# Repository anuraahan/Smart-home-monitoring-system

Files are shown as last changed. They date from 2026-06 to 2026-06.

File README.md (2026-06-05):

Node designs along with PCB and Schematic files in Node folder 
Node 2 is a better design with seperate ENS160 and AHT21 sensors so temperature less affected by heat from ENS160 
The code may have to be adjusted to get the right temp offset 
Screen code is an 2.8 inch ESP32-S3 from freenove 
https://docs.freenove.com/projects/fnk0104/en/latest/

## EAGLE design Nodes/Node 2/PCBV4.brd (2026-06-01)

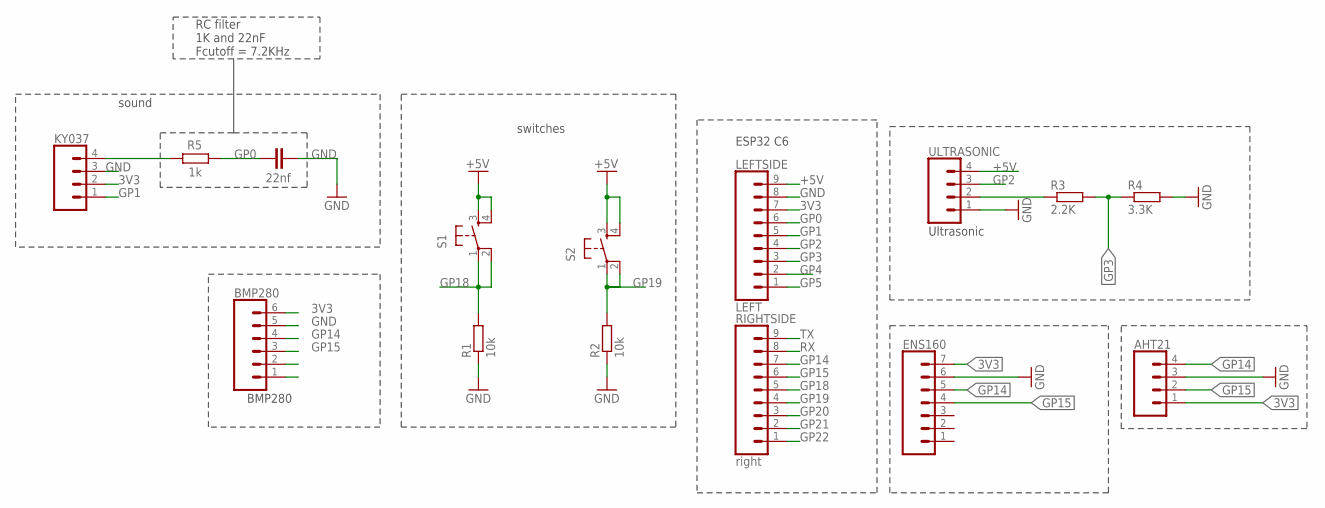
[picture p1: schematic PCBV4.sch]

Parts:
AHT21: CONN_04LONGPADS; 1X04_LONGPADS
BMP280: BMP280; SPARKFUN-CONNECTORS_1X06_LONGPADS
C1: 22nf; CAPACITOR-WIMA_C2.5-2
ENS160: CONN_07; 1X07
KY037: 1X04_SMD_STRAIGHT_COMBO; 1X04_LONGPADS
LEFTSIDE: LEFT; 1X09
R1, R2: 10k; 0207/10
R3: 2.2K; 0207/10
R4: 3.3K; 0207/10
R5: 1k; 0207/10
RIGHTSIDE: right; 1X09
S1, S2: EL311-ROBOT_SPARKFUN-ELECTROMECHANICAL_TAC_SWITCH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; EL311-ROBOT_SPARKFUN-ELECTROMECHANICAL_TACTILE-PTH
ULTRASONIC: 1X04_SMD_STRAIGHT_COMBO; 1X04_LONGPADS

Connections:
3V3: AHT21.1, BMP280.6, ENS160.7, KY037.2, LEFTSIDE.7
+5V: LEFTSIDE.9, S1.3, S1.4, S2.3, S2.4, ULTRASONIC.4
GND: AHT21.3, BMP280.5, C1.2, ENS160.6, KY037.3, LEFTSIDE.8, R1.1, R2.1, R4.2, ULTRASONIC.1
GP0: C1.1, LEFTSIDE.6, R5.1
GP1: KY037.1, LEFTSIDE.5
GP2: LEFTSIDE.4, ULTRASONIC.3
GP3: LEFTSIDE.3, R3.2, R4.1
GP4: LEFTSIDE.2
GP5: LEFTSIDE.1
GP14: AHT21.4, BMP280.4, ENS160.5, RIGHTSIDE.7
GP15: AHT21.2, BMP280.3, ENS160.4, RIGHTSIDE.6
GP18: R1.2, RIGHTSIDE.5, S1.1, S1.2
GP19: R2.2, RIGHTSIDE.4, S2.1, S2.2
GP20: RIGHTSIDE.3
GP21: RIGHTSIDE.2
GP22: RIGHTSIDE.1
unnamed: KY037.4, R5.2
unnamed: R3.1, ULTRASONIC.2
RX: RIGHTSIDE.8
TX: RIGHTSIDE.9

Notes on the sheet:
ESP32 C6
switches
Ultrasonic
BMP280
sound
RC filter 1K and 22nF Fcutoff = 7.2KHz

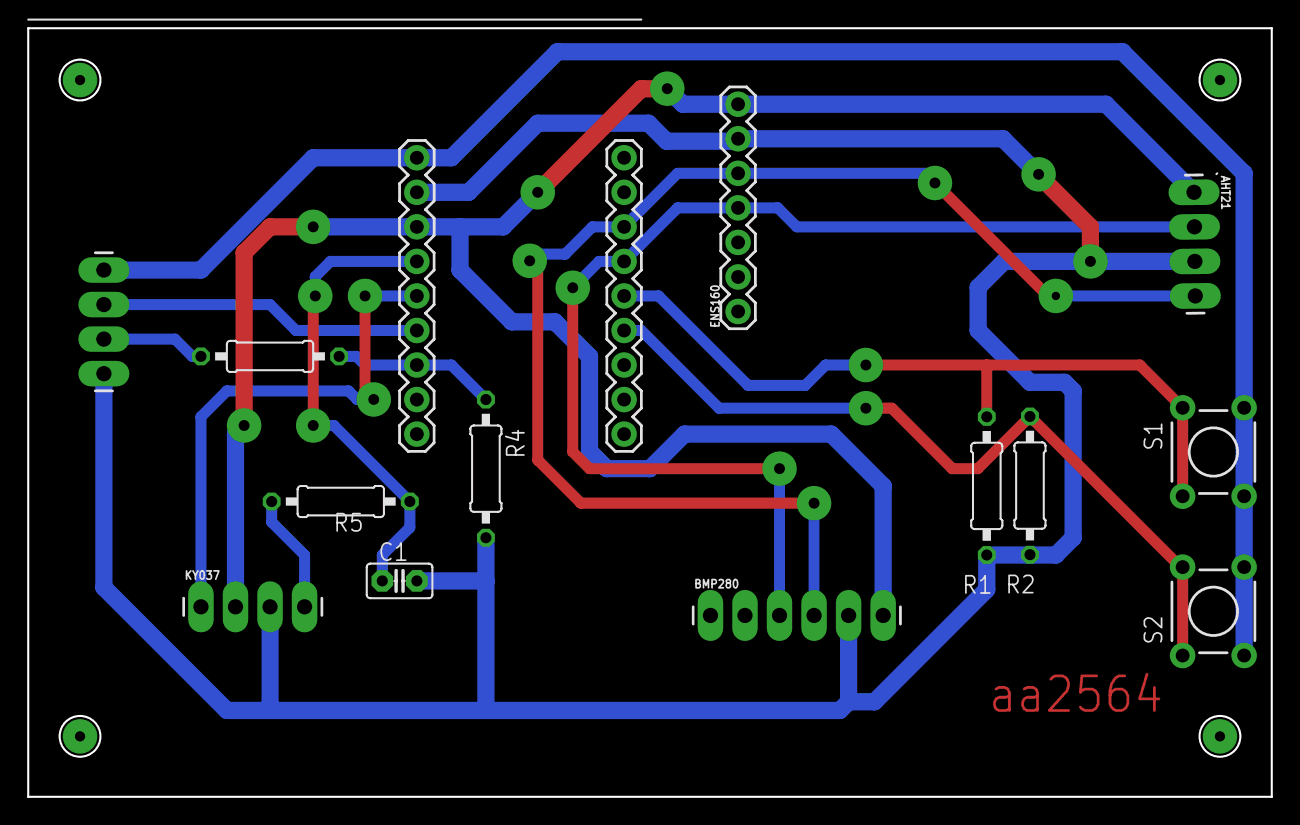
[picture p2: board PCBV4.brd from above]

Board: 2 copper layers, 91.4 x 56.5 mm, 15 parts (0 on the bottom side), 13 nets.

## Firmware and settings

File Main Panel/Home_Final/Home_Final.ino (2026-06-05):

/*
Smart Home Area Network (HAN) - Master Display & Server Node
Target Hardware: ESP32-S3 with TFT_eSPI Display, FT6336U Touch, and SD Card
This programme acts as a central hub, receiving JSON data from sensor nodes,
logging it to an SD card, displaying real-time metrics on a touchscreen GUI, 
and serving a web dashboard via an asynchronous web server.
 */

#include <WiFi.h>
#include <ESPAsyncWebServer.h>
#include <TFT_eSPI.h>
#include "FT6336U.h"
#include "FS.h"
#include "SD.h" 
#include "SPI.h"
#include "time.h" 
#include <ArduinoJson.h> 
#include "AsyncJson.h" // Required for ESPAsyncWebServer JSON extraction

// WiFi Configuration  
const char* ssid = "EDA-IOT";
const char* password = "3aB1J27M";
const char* API_KEY = "EDA_Secure_Key_2024"; // Security key for incoming JSON payloads

// Real-Time Clock (NTP) Synchronisation 
const char* ntpServer = "pool.ntp.org"; 
const long   gmtOffset_sec = 0;       
const int    daylightOffset_sec = 3600; // 1-hour offset for Daylight Saving Time (BST)

// Delay to allow gas/air quality sensors on the nodes to stabilise before reporting
const unsigned long WARMUP_DELAY_MS = 180000; // 3 minute warmup delay

// Custom SD Card SPI Pin Definitions
#define SD_SCK  38 
#define SD_MISO 39 
#define SD_MOSI 40 
#define SD_CS   47 
SPIClass spiSD(FSPI); // Initialise hardware SPI for the SD card

// Environmental & Tactical Threshold Configuration
// Index 0 = Node 1, Index 1 = Node 2
int soundThresholds[2]   = {500, 300}; 
float tempLow[2]         = {18.0, 18.0}; 
float tempHigh[2]        = {28.0, 30.0}; 
float humidLow[2]        = {30.0, 30.0}; 
float humidHigh[2]       = {70.0, 75.0}; 
float pressLow[2]        = {980.0, 980.0};   
float pressHigh[2]       = {1030.0, 1030.0}; 
int aqiThreshold[2]      = {3, 3}; 
float distChangeThreshold[2] = {15.0, 15.0}; // Trigger delta for ultrasonic obstacles

// Hardware Instantiation 
TFT_eSPI tft = TFT_eSPI(); // Instantiates the TFT display using User_Setup settings
FT6336U ft6336u(16, 15, 18, 17); // Touchscreen driver pins (SDA, SCL, RST, INT)
AsyncWebServer server(80); // Asynchronous web server running on port 80

//  Data Structures 
struct NodeData {  // Holds incoming data and evaluation states for each node
    float t=0, h=0, p=0, dst=0; // Temperature, humidity, pressure, distance
    int aqi=0, tvoc=0, eco2=0, snd=0; // Air quality indices and sound level
    // Detection flags (-1 = low alert, 0 = normal, 1 = high alert)
    int det_snd=0, det_temp=0, det_humid=0, det_press=0, det_aqi=0, det_dst=0; 
    float base_dst = 0; // Baseline distance for ultrasonic calibration
    int calib_count = 0; // Number of calibration readings taken
    unsigned long lastSeen = 0; // Timestamp of the last received packet
};

NodeData nodes[2]; // Array to store data for Node 1 and Node 2
int activeNode = 0, activePage = 0; // UI tracking variables

// UI State Tracking 
int lastPage = -1;
int lastNode = -1;
volatile bool forceFullRedraw = true; // Flag to force a complete screen refresh

volatile bool newDataReady = false;  // Flag set when new JSON data arrives
unsigned long lastStatusCheck = 0;
bool sdAvailable = false; // Tracks if the SD card successfully mounted

// Functions 

// Logs current node data to a CSV file on the SD card
void logDataToSD(int idx) { 
    if (!sdAvailable) return;
    struct tm timeinfo;
    char timeStr[30];
    
    // Attempt to get NTP time; fallback to millis() if time isn't synchronised yet
    if(!getLocalTime(&timeinfo)){
        sprintf(timeStr, "%lu", millis());
    } else {
        strftime(timeStr, sizeof(timeStr), "%Y-%m-%d %H:%M:%S", &timeinfo);
    }

    String fileName = (idx == 0) ? "/node1_log.csv" : "/node2_log.csv";
    File file = SD.open(fileName.c_str(), FILE_APPEND);
    if (!file) return; // Exit if file failed to open

    // Append a comma-separated row with timestamps and metrics
    file.printf("%s, %.2f, %.2f, %.2f, %d, %d, %d, %.1f, %d, %d\n", 
                timeStr, nodes[idx].t, nodes[idx].h, nodes[idx].p, 
                nodes[idx].aqi, nodes[idx].tvoc, nodes[idx].eco2, nodes[idx].dst, nodes[idx].snd, nodes[idx].det_dst);
    file.close();
}

// Evaluates incoming node data against predefined thresholds to set alert flags
void evaluateThresholds(int idx) { 
    NodeData &n = nodes[idx];
    
    // Evaluate sound levels
    n.det_snd = (n.snd > soundThresholds[idx]) ? 1 : 0;
    
    // Evaluate temperature (allows for cold and hot alerts)
    if (n.t < tempLow[idx]) {
        n.det_temp = -1;
    } else if (n.t > tempHigh[idx]) {
        n.det_temp = 1;
    } else {
        n.det_temp = 0;
    }
    
    // Evaluate humidity, pressure and AQI
    n.det_humid = (n.h < humidLow[idx] || n.h > humidHigh[idx]) ? 1 : 0;
    n.det_press = (n.p < pressLow[idx] || n.p > pressHigh[idx]) ? 1 : 0; 
    n.det_aqi = (n.aqi >= aqiThreshold[idx]) ? 1 : 0;
    
    // Evaluate ultrasonic distance and handle calibration
    if (n.calib_count < 5) { // Calibration stage: average the first 5 readings
        n.base_dst += n.dst;
        n.calib_count++; 
        if (n.calib_count == 5) {
            n.base_dst /= 5.0; // Calculate average baseline
            Serial.printf("Node %d Distance Calibrated: %.1f cm\n", idx + 1, n.base_dst);
            forceFullRedraw = true; // Update UI once calibrated
        }
    } else {
        // Compare current distance against the calibrated baseline
        if (abs(n.dst - n.base_dst) > distChangeThreshold[idx]) {
            n.det_dst = 1; // Obstacle detected
        } else {
            n.det_dst = 0; // Clear
        }
    }
}

// Generates the HTML, CSS, and JS for the web server dashboard
String getDashboardHTML() {
    // Basic HTML setup and styling (mimics the hardware TFT interface)
    String html = "<html><head><meta name='viewport' content='width=device-width, initial-scale=1.0'><style>";
    html += "body { font-family: 'Courier New', monospace; background: #000000; color: #FFFFFF; padding: 15px; margin: 0; }";
    html += ".screen-container { max-width: 600px; margin: 20px auto; border: 3px solid #333; background: #000000; box-shadow: 0 0 15px rgba(0,230,118,0.1); }";
    
    html += ".tft-header { background: #102008; border-bottom: 2px solid #333; padding: 10px; display: flex; justify-content: space-between; color: #7BEF; font-size: 14px; font-weight: bold; }";
    
    html += ".node-card { border: 1px solid #222; margin: 15px; background: #050505; }";
    html += ".node-title { background: #081018; padding: 8px 12px; font-size: 16px; border-bottom: 1px solid #222; display: flex; justify-content: space-between; }";
    html += ".section-title { color: #FFA500; font-size: 13px; font-weight: bold; letter-spacing: 1px; padding: 10px 15px 0 15px; text-transform: uppercase; text-align: left;}";
    html += ".grid-3 { display: grid; grid-template-columns: repeat(3, 1fr); gap: 10px; padding: 10px 15px 15px 15px; text-align: left; }";
    html += ".grid-2 { display: grid; grid-template-columns: repeat(2, 1fr); gap: 10px; padding: 10px 15px 15px 15px; text-align: left; }";
    
    html += ".val-group { background: #111; padding: 10px; border-radius: 2px; border-left: 3px solid #555; }";
    html += ".lbl { font-size: 11px; color: #888; text-transform: uppercase; margin-bottom: 4px; }";
    html += ".val { font-size: 18px; font-weight: bold; color: #FFFFFF; }";
    html += ".thresh-val { font-size: 14px; font-weight: bold; color: #FFFF00; }"; 
    
    // Dynamic styling for alerts and states
    html += ".online { color: #00FFFF; } .offline { color: #FF0000; }";
    html += ".alert-bg { border-left-color: #FF0000 !important; background: #200000 !important; }";
    html += ".alert-bg .val { color: #FF0000 !important; }";
    html += ".cold-bg { border-left-color: #0088FF !important; background: #001133 !important; }";
    html += ".cold-bg .val { color: #0088FF !important; }";
    html += ".alert-text { color: #FF0000 !important; font-weight: bold; animation: blink 1.5s infinite; }";
    html += ".safe-text { color: #008000; font-weight: bold; }";
    html += ".calib-text { color: #FFFF00; font-weight: bold; }";
    html += "@keyframes blink { 0% {opacity: 0.4;} 50% {opacity: 1;} 100% {opacity: 0.4;} }";
    
    // Sound bar graph CSS
    html += ".snd-bar-container { background: #222; border: 1px solid #FFF; height: 16px; width: 100%; position: relative; margin-top: 5px; }";
    html += ".snd-bar { height: 100%; width: 0%; transition: width 0.3s ease; }";
    html += "</style></head><body>";
    
    html += "<div class='screen-container'>";
    
    // Header containing IP and Time
    html += "  <div class='tft-header'>";
    html += "    <div>IP: " + WiFi.localIP().toString() + "</div>";
    html += "    <div id='sys-time'>00:00</div>";
    html += "  </div>";

    // Loop through both nodes to generate their respective dashboard cards
    for(int i=0; i<2; i++) {
        String num = String(i+1);
        int idx = i;
        html += "  <div class='node-card'>";
        html += "    <div class='node-title'><span>NODE " + num + "</span><span id='status-" + num + "' class='offline'>OFFLINE</span></div>";
        
        // Climate Section
        html += "    <div class='section-title'>CLIMATE</div>";
        html += "    <div class='grid-3'>";
        html += "      <div class='val-group' id='card-t-" + num + "'><div class='lbl'>Temp</div><div class='val' id='temp-" + num + "'>-</div></div>";
        html += "      <div class='val-group' id='card-h-" + num + "'><div class='lbl'>Humid</div><div class='val' id='humid-" + num + "'>-</div></div>";
        html += "      <div class='val-group' id='card-p-" + num + "'><div class='lbl'>Baro</div><div class='val' id='press-" + num + "'>-</div></div>";
        html += "    </div>";

        // Air Quality Section
        html += "    <div class='section-title'>AIR QUALITY</div>";
        html += "    <div class='grid-3'>";
        html += "      <div class='val-group' id='card-aqi-" + num + "'><div class='lbl'>AQI</div><div class='val' id='aqi-" + num + "'>-</div></div>";
        html += "      <div class='val-group'><div class='lbl'>TVOC</div><div class='val' id='tvoc-" + num + "'>-</div></div>";
        html += "      <div class='val-group'><div class='lbl'>eCO2</div><div class='val' id='eco2-" + num + "'>-</div></div>";
        html += "    </div>";

        // Tactical Sensors Section
        html += "    <div class='section-title'>TACTICAL SENSORS</div>";
        html += "    <div class='grid-3'>";
        html += "      <div class='val-group' id='card-dst-" + num + "' style='grid-column: span 2;'><div class='lbl'>Ultrasonic Distance</div><div class='val' id='dist-" + num + "'>-</div><div id='dist-msg-" + num + "' style='font-size:11px; margin-top:4px;'></div></div>";
        html += "      <div class='val-group' id='card-snd-" + num + "'><div class='lbl'>Sound</div><div class='val' id='sound-" + num + "'>-</div></div>";
        html += "    </div>";
        
        // Sound Graph Sub-section
        html += "    <div style='padding: 0 15px 15px 15px;'>";
        html += "      <div class='lbl'>Sound Decibel Matrix Graph</div>";
        html += "      <div class='snd-bar-container'><div class='snd-bar' id='sbar-" + num + "'></div></div>";
        html += "      <div id='sound-msg-" + num + "' style='font-size:11px; margin-top:5px; text-align:left;'></div>";
        html += "    </div>";

        // Threshold configuration display
        html += "    <div class='section-title' style='color:#FFFF00;'>THRESHOLDS MATRIX (PAGE 4 CONFIG)</div>";
        html += "    <div class='grid-2' style='background:#0a0a0a; border-top: 1px dashed #222;'>";
        html += "      <div class='val-group' style='border-left: 2px solid #FFFF00;'><div class='lbl'>Sound Max</div><div class='thresh-val'>" + String(soundThresholds[idx]) + "</div></div>";
        html += "      <div class='val-group' style='border-left: 2px solid #FFFF00;'><div class='lbl'>Temp Limits</div><div class='thresh-val'>" + String(tempLow[idx],1) + " - " + String(tempHigh[idx],1) + " C</div></div>";
        html += "      <div class='val-group' style='border-left: 2px solid #FFFF00;'><div class='lbl'>Humid Limits</div><div class='thresh-val'>" + String(humidLow[idx],0) + " - " + String(humidHigh[idx],0) + "%</div></div>";
        html += "      <div class='val-group' style='border-left: 2px solid #FFFF00;'><div class='lbl'>Baro Limits</div><div class='thresh-val'>" + String(pressLow[idx],0) + " - " + String(pressHigh[idx],0) + " hPa</div></div>";
        html += "      <div class='val-group' style='border-left: 2px solid #FFFF00; grid-column: span 2;'><div class='lbl'>Distance Delta Change Trigger</div><div class='thresh-val'>" + String(distChangeThreshold[idx],1) + " cm</div></div>";
        html += "    </div>";
        
        html += "  </div>";
    }
    
    // Footer containing system status
    html += "  <div class='tft-header' style='border-top:2px solid #333; border-bottom:none; color:#888; font-size:12px;'>";
    html += "    <div id='sd-log-status'>SD LOGGING: " + String(sdAvailable ? "ACTIVE" : "FAILED") + "</div>";
    html += "    <div>TARGET PROFILE: HYBRID MULTI-NODE</div>";
    html += "  </div>";
    html += "</div>";

    // JavaScript for asynchronous data fetching and DOM updates
    html += "<script>";
    html += "async function updateDashboard() {";
    html += "  try {";
    html += "    let res = await fetch('/api/data');"; // Fetch data from local API endpoint
    html += "    let data = await res.json();";
    html += "    let d = new Date();";
    html += "    document.getElementById('sys-time').innerText = String(d.getHours()).padStart(2,'0') + ':' + String(d.getMinutes()).padStart(2,'0');";
    html += "    data.forEach((node, i) => {";
    html += "      let idx = i + 1;";
    html += "      let statusEl = document.getElementById('status-'+idx);";
    html += "      statusEl.innerText = node.online ? 'ONLINE' : 'OFF';";
    html += "      statusEl.className = node.online ? 'online' : 'offline';";
    html += "      ";
    html += "      document.getElementById('temp-'+idx).innerText = node.t.toFixed(1) + ' C';";
    
    // Apply background classes based on detection states
    html += "      let tClass = 'val-group';";
    html += "      if (node.det_t === -1) tClass += ' cold-bg';";
    html += "      else if (node.det_t === 1) tClass += ' alert-bg';";
    html += "      document.getElementById('card-t-'+idx).className = tClass;";
    
    html += "      ";
    html += "      document.getElementById('humid-'+idx).innerText = node.h.toFixed(0) + '%';";
    html += "      document.getElementById('card-h-'+idx).className = 'val-group' + (node.det_h ? ' alert-bg' : '');";
    html += "      ";
    html += "      document.getElementById('press-'+idx).innerText = node.p.toFixed(0) + ' hPa';";
    html += "      document.getElementById('card-p-'+idx).className = 'val-group' + (node.det_p ? ' alert-bg' : '');";
    html += "      ";
    html += "      document.getElementById('aqi-'+idx).innerText = node.aqi;";
    html += "      document.getElementById('card-aqi-'+idx).className = 'val-group' + (node.det_aqi ? ' alert-bg' : '');";
    html += "      ";
    html += "      document.getElementById('tvoc-'+idx).innerText = node.tvoc + ' ppb';";
    html += "      document.getElementById('eco2-'+idx).innerText = node.eco2 + ' ppm';";
    html += "      ";
    
    // Manage Ultrasonic calibration UI state
    html += "      let dMsg = document.getElementById('dist-msg-'+idx);";
    html += "      if(node.cal < 5){";
    html += "         document.getElementById('dist-'+idx).innerText = 'CALIB';";
    html += "         dMsg.innerText = 'CALIBRATING...'; dMsg.className='calib-text';";
    html += "      } else {";
    html += "         document.getElementById('dist-'+idx).innerText = node.dst.toFixed(1) + ' cm';";
    html += "         dMsg.innerText = node.det_d ? '! OBSTACLE DETECTED !' : 'STATUS: CLEAR';";
    html += "         dMsg.className = node.det_d ? 'alert-text' : 'safe-text';";
    html += "      }";
    html += "      document.getElementById('card-dst-'+idx).className = 'val-group' + (node.det_d ? ' alert-bg' : '');";
    html += "      ";
    
    // Manage Sound Bar width and colour
    html += "      document.getElementById('sound-'+idx).innerText = node.snd;";
    html += "      document.getElementById('card-snd-'+idx).className = 'val-group' + (node.det_s ? ' alert-bg' : '');";
    html += "      let pct = Math.min((node.snd / 1000) * 100, 100);";
    html += "      let sBar = document.getElementById('sbar-'+idx); sBar.style.width = pct + '%';";
    html += "      sBar.style.background = node.det_s ? '#FF0000' : '#008000';";
    html += "      let sMsg = document.getElementById('sound-msg-'+idx);";
    html += "      sMsg.innerText = node.det_s ? '! SOUND DETECTED !' : 'STATUS: QUIET';";
    html += "      sMsg.className = node.det_s ? 'alert-text' : 'safe-text';";
    html += "    });";
    html += "  } catch(e) { console.error('Data pull error', e); }";
    html += "}";
    html += "setInterval(updateDashboard, 2000); updateDashboard();"; // Poll every 2 seconds
    html += "</script></body></html>";
    return html;
}
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
void loop() {
    // Refresh the UI if new JSON data arrived or periodically every 1 second
    if (millis() - lastStatusCheck > 1000 || newDataReady) { 
        refreshUI(); lastStatusCheck = millis(); newDataReady = false; 
    }
    
    // Poll the FT6336U touchscreen for user input
    FT6336U_TouchPointType tp = ft6336u.scan(); 
    if (tp.touch_count > 0) {
        // Map touch coordinates (display rotation must be accounted for)
        int tx = tp.tp[0].y; 
        int ty = 240 - tp.tp[0].x;
        
        // Touch zone detection: bottom of the screen
        if (ty > 200) {
            // Node toggle button area (bottom left)
            if (tx < 140) activeNode = (activeNode == 0) ? 1 : 0;
            // Page left arrow area
            else if (tx > 230 && tx < 270 && activePage > 0) activePage--;
            // Page right arrow area
            else if (tx > 275 && activePage < 4) activePage++;
            
            forceFullRedraw = true; // Input registered, redraw layout
            refreshUI(); 
            delay(250); // Debounce delay
        }
    }
}

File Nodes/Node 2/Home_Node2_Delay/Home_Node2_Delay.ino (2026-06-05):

 
#include <WiFi.h>              // Handles Wi-Fi connectivity for the ESP32
#include <HTTPClient.h>        // Enables sending HTTP POST requests to the server
#include <Wire.h>              // I2C communication library for sensors
#include <Adafruit_BMP280.h>   // Library for the BMP280 barometric pressure sensor
#include "DFRobot_ENS160.h"    // Library for the ENS160 air quality sensor
#include <Adafruit_AHTX0.h>    // Library for the AHT20/AHT10 temperature & humidity sensor
#include <Adafruit_NeoPixel.h> // Library for the WS2812 RGB LED (status indicator)
#include <ArduinoJson.h>       // Added for Structured Payloads (JSON formatting)

// CONFIGURATION 
const char* ssid = "EDA-IOT";                 // Wi-Fi network SSID
const char* password = "3aB1J27M";            // Wi-Fi network password
const char* serverUrl = "http://10.150.46.120/update"; // Endpoint for data ingestion
const char* API_KEY = "EDA_Secure_Key_2024";  // Security key for API authentication


// NODE 2 SETTINGS
const char* nodeID = "node2";       // Unique identifier for this specific hardware node
#define SOUND_ATTENUATION ADC_6db   // Sets analogue-to-digital converter (ADC) gain for the sound pin
float tempOffset = -2;              // Calibration offset for temperature readings (in Celsius)
float humidOffset = 6.0;            // Calibration offset for humidity readings (in %)
int cycleTime = 2300;               // Interval between data transmissions (in milliseconds)
float alpha = 0.25;                 // Smoothing factor for the Exponential Moving Average (EMA) filter

const unsigned long WARMUP_DURATION = 180000; // 3-minute warm-up time required for the ENS160 gas sensor


// HARDWARE PINS 
#define SOUND_PIN 0                 // Analogue pin connected to the sound sensor
#define TRIG_PIN 2                  // Digital pin to trigger the ultrasonic sensor
#define ECHO_PIN 3                  // Digital pin to read the ultrasonic sensor echo
#define CALIB_BTN 18                // Digital pin for the physical calibration button
#define SDA_PIN 15                  // I2C Data pin
#define SCL_PIN 14                  // I2C Clock pin

// Initialise the NeoPixel string (1 pixel, connected to pin 8)
Adafruit_NeoPixel pixels(1, 8, NEO_GRB + NEO_KHZ800);

// Helper function to set the colour of the status NeoPixel
void setPixel(uint8_t r, uint8_t g, uint8_t b) {
  pixels.setPixelColor(0, pixels.Color(r, g, b));
  pixels.show(); // Push the updated colour to the hardware
}

// Instantiate sensor objects
Adafruit_BMP280 bmp;
Adafruit_AHTX0 aht;
DFRobot_ENS160_I2C ENS160(&Wire, (uint8_t)0x53); // ENS160 requires the I2C address (0x53)

// Timing and state variables
unsigned long lastCycle = 0;             // Tracks the last time data was transmitted
volatile bool flag_calibrate = false;    // Volatile flag to safely share state between the ISR and main loop

// SOUND LATCHING VARIABLES 
int peakSoundEnergy = 0;                 // Holds the maximum sound amplitude detected within a cycle
float currentMidpoint = 2048.0;          // Running midpoint of the sound waveform (12-bit ADC: max 4095)
float baseline = 2048.0;                 // Fixed baseline to calculate amplitude against

// HISTORICAL TRACKING REGISTERS FOR EMA SMOOTHING 
float smoothTemp = 25.0;                 // Smoothed temperature value
float smoothHumidity = 50.0;             // Smoothed humidity value
float smoothPressure = 1013.25;          // Smoothed barometric pressure value (standard sea-level pressure default)
bool firstRun = true;                    // Flag to bypass smoothing on the very first reading

// Interrupt Service Routine (ISR) triggered by pressing the calibration button
void IRAM_ATTR handleCalibPress() {
  flag_calibrate = true; // Set flag to true to notify the main loop
}

// Function to get a reliable distance measurement using an ultrasonic burst technique
float getDistanceBurst() {
  float readings[5];
  // Take 5 distinct measurements to form a statistical sample
  for (int i = 0; i < 5; i++) {
    digitalWrite(TRIG_PIN, LOW); delayMicroseconds(2);   // Ensure trigger is low
    digitalWrite(TRIG_PIN, HIGH); delayMicroseconds(10); // Send 10 microsecond acoustic pulse
    digitalWrite(TRIG_PIN, LOW);
    
    // Measure how long it takes for the echo to return (timeout after 30ms)
    long duration = pulseIn(ECHO_PIN, HIGH, 30000); 
    // If timeout (duration == 0), default to max distance (400 cm), else calculate distance
    readings[i] = (duration == 0) ? 400.0 : (duration * 0.034 / 2); 
    delay(10); // Brief pause before next ping
  }
  
  // Sort the array of 5 readings in ascending order (simple bubble sort)
  for(int i=0; i<4; i++) {
    for(int j=i+1; j<5; j++) {
      if(readings[i] > readings[j]) {
        float temp = readings[i]; readings[i] = readings[j]; readings[j] = temp;
      }
    }
  }
  
  // Discard the highest and lowest readings (outliers) and return the average of the middle three
  return (readings[1] + readings[2] + readings[3]) / 3.0;
}

void setup() {
  Serial.begin(115200); // Initialise serial communication for debugging
  delay(50);
  
  pinMode(LED_BUILTIN, OUTPUT);
  
  // Initialise the status NeoPixel to red (indicating setup phase)
  pixels.begin();       
  setPixel(150, 0, 0); 

  // Initialise I2C bus with custom pins
  Wire.begin(SDA_PIN, SCL_PIN);
  
  // Configure sensor pins
  pinMode(SOUND_PIN, INPUT);
  pinMode(TRIG_PIN, OUTPUT);
  pinMode(ECHO_PIN, INPUT);
  
  // Configure calibration button with internal pull-up and attach hardware interrupt
  pinMode(CALIB_BTN, INPUT_PULLUP);
  attachInterrupt(digitalPinToInterrupt(CALIB_BTN), handleCalibPress, FALLING); // Trigger when button pulls voltage to ground
  
  // Configure ESP32 analogue settings
  analogReadResolution(12); // Set ADC resolution to 12 bits (0-4095 range)
  analogSetPinAttenuation(SOUND_PIN, SOUND_ATTENUATION); // Set signal attenuation for the mic

  // Initialise BMP280 Pressure Sensor. Halt and stay red if it fails.
  if (!bmp.begin(0x76)) {
    setPixel(150, 0, 0);  
    while (1) { delay(10); } 
  }

  // Initialise AHT20 Temp/Humidity Sensor. Halt and stay red if it fails.
  if (!aht.begin()) { 
    setPixel(150, 0, 0);  
    while (1) { delay(10); } 
  }

  // Initialise ENS160 Gas Sensor. Flash yellow whilst trying to connect.
  while (ENS160.begin() != 0){
    setPixel(150, 150, 0); 
    delay(1000);
  }
  ENS160.setPWRMode(ENS160_STANDARD_MODE); // Set sensor to standard operation mode

  // Calculate the initial analogue baseline for the sound sensor
  long sum = 0;
  for(int i=0; i<300; i++) { sum += analogRead(SOUND_PIN); delay(2); }
  baseline = sum / 300.0;       // Average of 300 readings
  currentMidpoint = baseline;   // Initialise the running midpoint

  // Connect to the Wi-Fi network
  WiFi.mode(WIFI_STA);
  WiFi.begin(ssid, password);
}
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

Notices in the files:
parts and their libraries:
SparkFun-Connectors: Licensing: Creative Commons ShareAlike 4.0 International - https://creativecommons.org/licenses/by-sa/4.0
